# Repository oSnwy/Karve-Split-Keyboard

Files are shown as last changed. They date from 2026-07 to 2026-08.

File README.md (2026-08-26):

# Karve-Split-Keyboard

## What is this?
This is a keyboard, designed to be slightly ergonomic-consious while keeping the orginal layout and familarity of an 80% keyboard. The idea is to create a split keyboard, but with the option to connect the two havles together to create a regular 80% keyboard, inspired from the [Epomaker Split 65](https://epomaker.com/products/epomaker-split-65). Unlike the Split 65, this features an 80% layout with macro keys on the left column, an OLED 0.91 inch screen and rotary encoder on both sides. While making this keyboard, I realized that the format is really similar to the [Keychron Q11](https://www.keychron.com/products/keychron-q11-qmk-custom-mechanical-keyboard) with the macro keys and 80% layout. This keyboard features an unexploded (is that the right term) layout, maximizing desk space without comprimising on the number of keys (I need my precious function row). 

Each side of the keyboard is powered by an Pi Pico with an RP2040. The descision behind the RP2040 was due to the number of GPIO pins. Other options such as the nrf52840 and the RP2040-Zero would've worked well for this project, but the number of GPIO pins wouldn't be sufficient for all the switches and the extra features on the keyboard. The OLED screen is a general 0.91 inch 128x32px screen, with optional footprints for pull-up resistors, and the rotary encoder is a regular EC11 push switch. The switches in the keyboard are wired in a matrix with a diode on each switch. The left side is wired as an 8x6 matrix, and the right side is an 9x6 matrix. The switches themselves contain a regular mx hotswap socket which allows for easy switching between switches of the same format.

## How do I get this?
For this keyboard, you need the pcb, switches, stablizers, keycaps, two Pi Picos, two OLED screens and two rotary encoders. You should order the rest of the components using the PCBA option on [JLCPCB](https://jlcpcb.com/). You can order it using the gerbers zip file in the Gerbers file, as well as the [bom.csv](https://github.com/oSnwy/Karve-Split-Keyboard/blob/main/csv%20files/bom.csv) and the [positions-full-pcb-offset.csv](https://github.com/oSnwy/Karve-Split-Keyboard/blob/main/csv%20files/positions-full-pcb-offset.csv). Make sure you choose bottom side assembly. The switches simply slide into the top of the plate and fit into the hotswap sockets on the PCB, the stablizers are plate mounted and can be slotted into the plate, and the keycaps simply go on top of the switches. The plate uses spacers to attach to both the PCB and the case using self-tapping screws through the plate, without the need for unnessecary mounting holes on the thin plate, which may degrade it's strength. The OLED screen and Pi Pico must be soldered into the PCB using the pins, making sure they are in the correct orientation.

## CAD
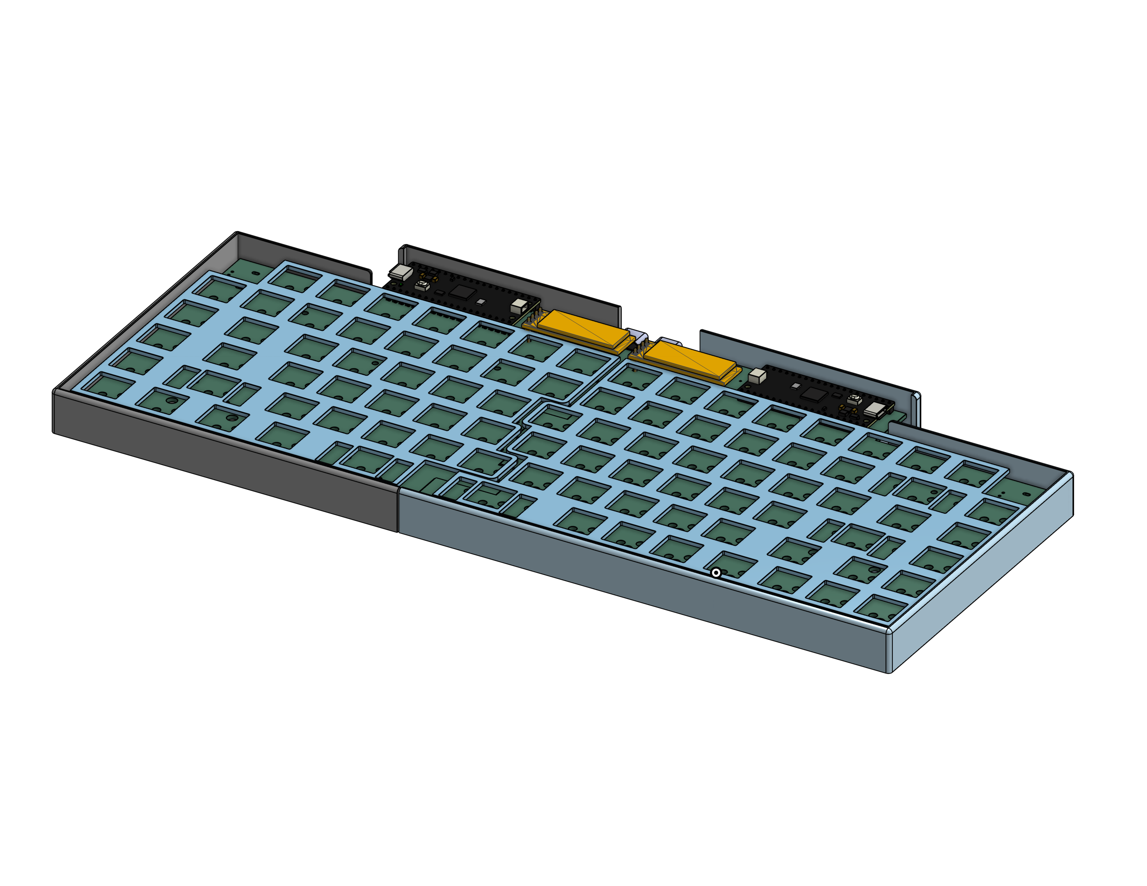
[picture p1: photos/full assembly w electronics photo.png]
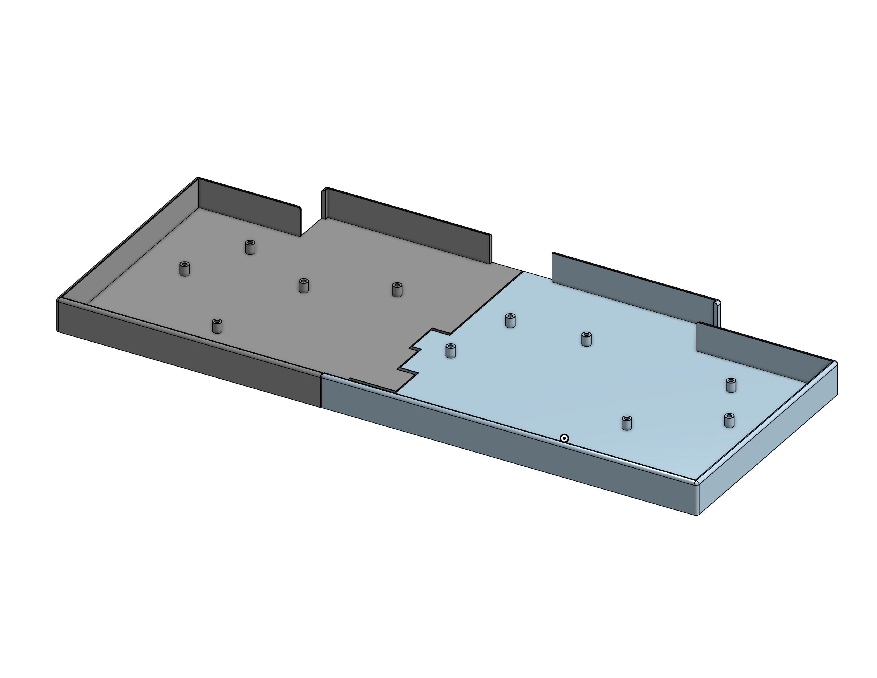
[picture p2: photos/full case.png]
|  |  |
| - | - |

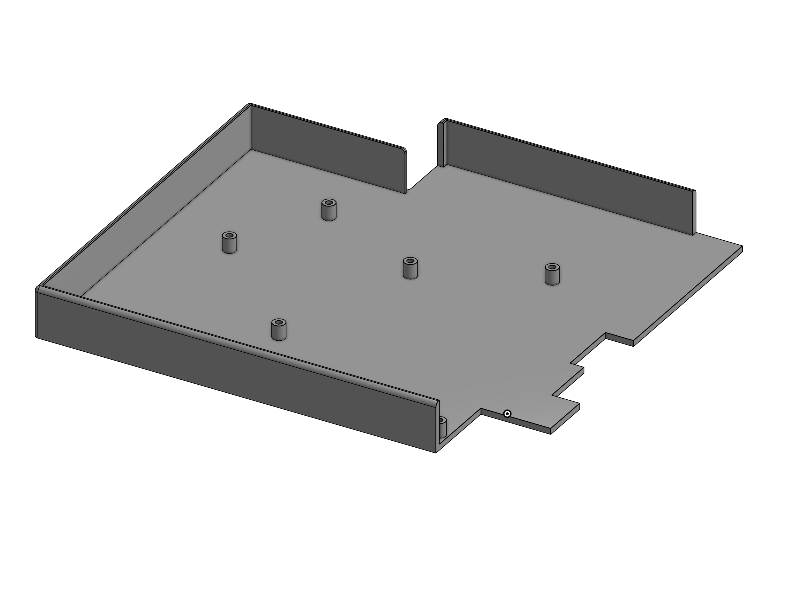
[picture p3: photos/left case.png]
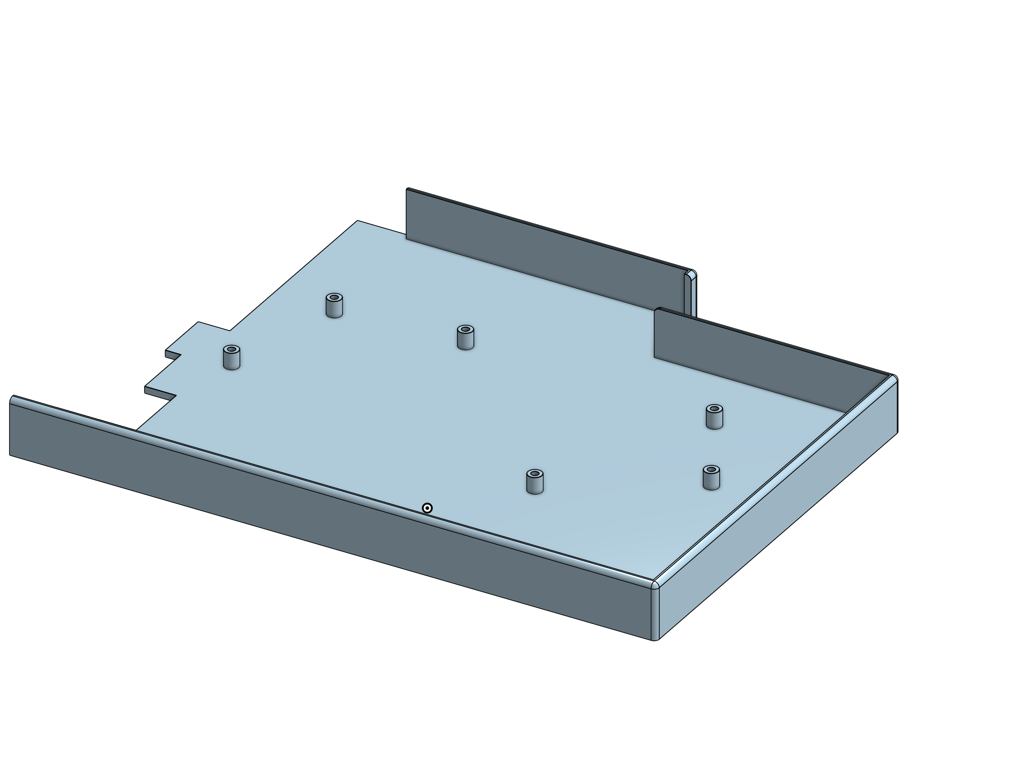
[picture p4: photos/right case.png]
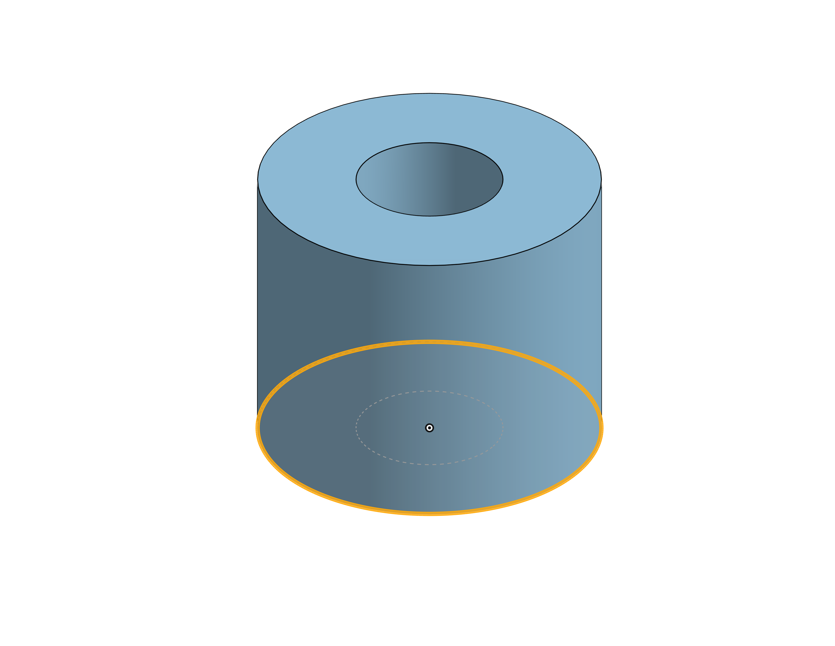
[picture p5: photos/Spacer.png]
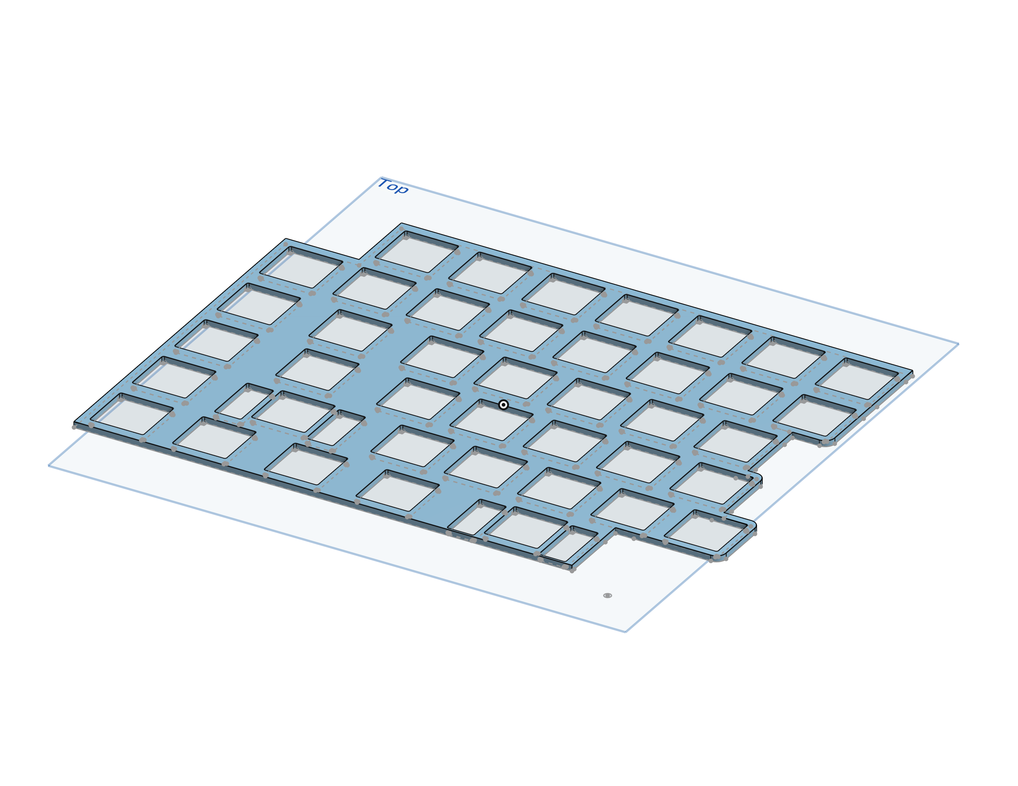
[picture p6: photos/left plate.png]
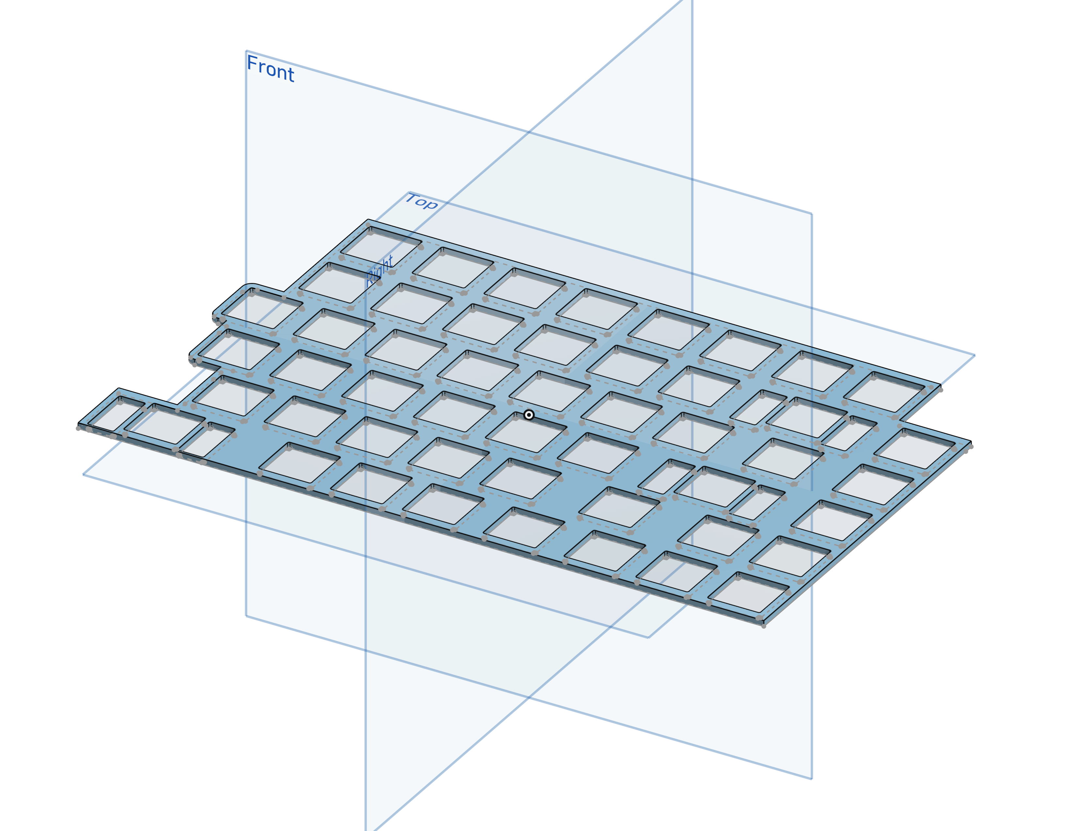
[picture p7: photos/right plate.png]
|  |  |  |  |  |
| - | - | - | - | - |

This keyboard is printed in two parts, with two different cases for each half of the PCB, as well as two plates for each half the plate and pcb are seperated by 3.5mm spacers, which are screwed in from the top of the plate to the PCB mounting holes.

[ONSHAPE LINK](https://cad.onshape.com/documents/be21bbec0bd274685795aaea/w/a2ca9be3fdf7d240859b7480/e/7d2817619a652fb02e73bd80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)

## Schematic
|  | | 
| - | - |

The schematic contains a matrix for the switches on each side, a simple 4 pin OLED screen with pull-up resistors that can be unpopulated if the screen already has pull-ups, a USB-C UART connector between the two halves, and a fuse and capacitor for the power line. The USB-C UART connections works by splitting the TX and RX lines, as well as passing the 5v through the VSYS and passing the ground through the wire.

## PCB


The PCB is a simple PCB with traces of varying widths for the purpose of each trace. The power lines and ground lines for the USB-C receptacle were 0.75mm, other ground traces and local power lines are 0.5mm. The PCB also includes M2 holes for the mounting and mousebites so the PCB can be ordered as one part.
|  | | 
| - | - |

The silkscreen art is put togetrher in a way that (hopefully) will show a full image of the tree when the split halves are put together.
## BOM

### JLCPCB BOM
 Qty | References | Component | Manufacturer / Part number | PCB footprint | JLCPCB part | Library |
|---:|---|---|---|---|---|---|
| 2 | `C2, C3` | 10 µF, 50 V, X5R, ±10% ceramic capacitor | Murata `GRM21BR61H106KE43L` | `0805` | [C440198](https://jlcpcb.com/partdetail/439567-GRM21BR61H106KE43L/C440198) | Basic |
| 92 | `D43–D134` | 1 A, 200 V fast-recovery diode | DOWO `ES1D (SOD-123FL)` | `SOD-123FL` | [C22374920](https://jlcpcb.com/partdetail/DOWO-ES1D_SOD_123FL/C22374920) | Extended |
| 2 | `F2, F3` | 500 mA resettable fuse, 33 V | BHFUSE `BSMD1206-050-33V` | `1206` | [C7202014](https://jlcpcb.com/partdetail/BHFUSE-BSMD1206_05033V/C7202014) | Extended |
| 2 | `J2, J3` | USB-C 2.0 receptacle, 16-pin | Korean Hroparts `TYPE-C-31-M-12` | `USB_C_Receptacle_HRO_TYPE-C-31-M-12` | [C165948](https://jlcpcb.com/partdetail/Korean_HropartsElec-TYPE_C_31_M12/C165948) | Extended |
| 2 | `R5, R6` | 47 Ω, ±1%, 100 mW resistor | UNI-ROYAL `0603WAF470JT5E` | `0603` | [C23182](https://jlcpcb.com/partdetail/23909-0603WAF470JT5E/C23182) | Basic |
| 90 | `SW43–SW50`, `SW52–SW92`, `SW94–SW134` | MX-compatible hot-swap socket | HanElectricity `CPG151101S11-16` | See variants below | [C41430893](https://jlcpcb.com/partdetail/HanElectricity-CPG151101S1116/C41430893) | Extended |

<details>
<summary>Hot-swap footprint variants</summary>

| Footprint | Qty |
|---|---:|
| `MX100H` | 77 |
| `MX125H` | 4 |
| `MX150H` | 2 |
| `MX175H` | 2 |
| `MX200H` | 1 |
| `MX225H` | 3 |
| `MX275H` | 1 |
| **Total** | **90** |

</details> 

### PCB and PCBA
| Component | Quantity | Notes / specification | Link | Cost |
|---|---:|---|---|---:|
| Custom split-keyboard PCB set | 1  | Left and right PCB (together) | [JLCPCB](https://jlcpcb.com/) | $64.59 USD |
| Raspberry Pi Pico | 2 | RP2040 USB-C Clone | [LINK](https://www.aliexpress.com/item/1005009245863235.html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) | $8.09 USD |
| Kailh MX-compatible hot-swap socket | 90 | HanElectricity `CPG151101S11-16`; JLCPCB/LCSC `C41430893` | [JLCPCB](https://jlcpcb.com/partdetail/HanElectricity-CPG151101S1116/C41430893) | Included in PCBA |
| Matrix diode | 92 | DOWO `ES1D`, SOD-123FL, 1 A, 200 V; JLCPCB/LCSC `C22374920` | [JLCPCB](https://jlcpcb.com/partdetail/DOWO-ES1D_SOD_123FL/C22374920) | Included in PCBA |
| USB-C 2.0 receptacle | 2 | Korean Hroparts `TYPE-C-31-M-12`; JLCPCB/LCSC `C165948` | [JLCPCB](https://jlcpcb.com/partdetail/TYPE-C-31-M-12/C165948) | Included in PCBA |
| Resettable polyfuse | 2 | BHFUSE `BSMD1206-050-33V`, 500 mA; JLCPCB/LCSC `C7202014` | [JLCPCB](https://jlcpcb.com/partdetail/BHFUSE-BSMD1206_05033V/C7202014) | Included in PCBA |
| 10 µF ceramic capacitor | 2 | Murata `GRM21BR61H106KE43L`, 0805, 50 V, X5R; JLCPCB/LCSC `C440198` | [JLCPCB](https://jlcpcb.com/partdetail/439567-GRM21BR61H106KE43L/C440198) | Included in PCBA |
| 47 Ω resistor | 2 | UNI-ROYAL `0603WAF470JT5E`, 0603, ±1%; JLCPCB/LCSC `C23182` | [JLCPCB](https://jlcpcb.com/partdetail/23909-0603WAF470JT5E/C23182) | Included in PCBA |
| 4.7 kΩ pull-up resistor | 4 optional | Through-hole; only install if the OLED modules do not include I²C pull-ups | Optional | N/A |

### Displays and Controls

| Component | Quantity | Notes / specification | Link | Cost |
|---|---:|---|---|---:|
| 0.91-inch I²C OLED display | 2 | pin order and pull ups | [AliExpress](https://www.aliexpress.com/item/1005008640108394.html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) | $7.70 USD |
| EC11-style rotary encoder with push switch | 2 | EC11 Footprint | [AliExpress](https://www.aliexpress.com/item/1005005622580163.html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) | $3.35 USD |

### Switches and Keycaps

| Component | Quantity | Notes / specification | Link | Cost |
|---|---:|---|---|---:|
| MX-compatible mechanical switch | 90 | 5-pin PCB-mount switches recommendeds | [AliExpress](https://www.aliexpress.com/item/1005005888884109.html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) | $22.53 USD |
| Keycap set | 1 set | Must cover the full split layout and split spacebar | [AliExpress](https://www.aliexpress.com/item/1005009105824301.html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) | $27.45 USD |
| Stabilizers | As required | Required for stabilized keys | [AliExpress](https://www.aliexpress.com/item/1005005793408621.html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) | $10.72 USD |

### Case, Plate, and Mounting Hardware

| Component | Quantity | Notes / specification | Link | Cost |
|---|---:|---|---|---:|
| Left keyboard plate | 1 | 3d printed | N/A | N/A |
| Right keyboard plate | 1 | 3d printed | N/A | N/A |
| Left keyboard case | 1 | 3d printed | N/A | N/A |
| Right keyboard case | 1 | 3d printed | N/A | N/A |
| Spacers | 16 | 3d pritned | N/A | N/A |

### Pico and Display Installation Hardware

| Component | Quantity | Notes / specification | Link | Cost |
|---|---:|---|---|---:|
| 1×20 pin headers | 4 strips | Two rows per Pico if soldering through-hole headers | COMES WITH PI PICO | FREE |
| 1×4 pin headers | 2 | For directly soldering the OLED modules | COMES WITH OLED | FREE |

### Cost Summary

| Category | Cost |
|---|---:|
| PCB fabrication  | $29.90 USD |
| PCB components and assembly | $34.69 USD |
| Picos, displays, and encoders | $19.14 USD |
| Switches and keycaps | $49.98 USD |
| Case, plates, and hardware | N/A |
| Cables and assembly supplies | $10.72 |
| Shipping and taxes | $41.25 USD |
| **Estimated total** | **$185.68 USD** |

## Firmware
This firmware is the preliminary firmware, and may be changed for the final finished build. It uses QMK, and can be flashed using UF2 and QMK commands.
I used this repositry as a reference: https://github.com/aminch/c64p/tree/main, as well as a couple other websites.

The firmware is grouped under the firmware file in the repositry.
It includes:
| File | Purpose |
| - | - |
| info.json | tells the computer what keyboard/mcu, as well as the USB type. |
| rules.mk | tells the computer what QMK features should be used, such as the I2C OLED. |
| mcuconf.h | enables the rp2040 I2C hardware for the OLED screens. |
| halconf.h | also used to enable the I2C for the OLED screens. |
| config.h | used to define all the pins on the picos for both the left and right split halves, as well as other features such as debounce time, OLED brightness, etc. |
| keymap.c | used to define the keymap as well as the OLED, encoders, as well as layers. |

### rules.mk: 
``` C
MCU = RP2040
BOARD = GENERIC_RP_RP2040
BOOTLOADER = rp2040

ENCODER_ENABLE = yes
OLED_ENABLE = yes
OLED_DRIVER = ssd1306
OLED_TRANSPORT = i2c
```
These lines are used to define the MCU, board, as well as enable rotary encoders and OLED screens.

### config.h: 
``` C
#define DIODE_DIRECTION COL2ROW

#define MATRIX_ROW_PINS { GP8, GP9, GP10, GP11, GP12, GP13 }
#define MATRIX_COL_PINS { GP0, GP1, GP2, GP3, GP4, GP5, GP6, GP7, NO_PIN }

#define MATRIX_ROW_PINS_RIGHT { GP5, GP4, GP3, GP2, GP1, GP0 }
#define MATRIX_COL_PINS_RIGHT { GP14, GP13, GP12, GP11, GP10, GP9, GP8, GP7, GP6 }

#define ENCODER_A_PINS { GP20 }
#define ENCODER_B_PINS { GP21 }
#define ENCODER_A_PINS_RIGHT { GP20 }
#define ENCODER_B_PINS_RIGHT { GP21 }

#define SERIAL_USART_FULL_DUPLEX
#define SERIAL_USART_TX_PIN GP16
#define SERIAL_USART_RX_PIN GP17

#define I2C_DRIVER I2CD1
#define I2C1_SDA_PIN GP18
#define I2C1_SCL_PIN GP19
```
This is used to define what each pin is used for, such as the matrix, encoders, as bwell as TX/RX and pins used for the OLED screen etc. The RX/TX are crossed through the USB port, so both sides can have the same RX/TX pins. 

``` C
#define EE_HANDS
```
This means that both of the source codes are the same for both the left and right side.

### keymap.c:
``` C
const uint16_t PROGMEM keymaps[][MATRIX_ROWS][MATRIX_COLS] = {
    [_BASE] = {
        { KC_MUTE, KC_ESC,  KC_F1,   KC_F2,   KC_F3,   KC_F4,   KC_F5,   KC_F6,   KC_NO },
        { KC_F13,  KC_GRV,  KC_1,    KC_2,    KC_3,    KC_4,    KC_5,    KC_6,    KC_NO },
        { KC_F14,  KC_TAB,  KC_Q,    KC_W,    KC_E,    KC_R,    KC_T,    KC_NO,   KC_NO },
        { KC_F15,  KC_CAPS, KC_A,    KC_S,    KC_D,    KC_F,    KC_G,    KC_NO,   KC_NO },
        { KC_F16,  KC_LSFT, KC_Z,    KC_X,    KC_C,    KC_V,    KC_B,    KC_NO,   KC_NO },
        { KC_F17,  KC_LCTL, KC_LGUI, KC_LALT, KC_SPC,  KC_NO,   KC_NO,   KC_NO,   KC_NO },
        { KC_F7,   KC_F8,   KC_F9,   KC_F10,  KC_F11,  KC_F12,  KC_INS,  KC_DEL,  KC_MUTE },
        { KC_NO,   KC_7,    KC_8,    KC_9,    KC_0,    KC_MINS, KC_EQL,  KC_BSPC, KC_PGUP },
        { KC_Y,    KC_U,    KC_I,    KC_O,    KC_P,    KC_LBRC, KC_RBRC, KC_BSLS, KC_PGDN },
        { KC_NO,   KC_H,    KC_J,    KC_K,    KC_L,    KC_SCLN, KC_QUOT, KC_ENT,  KC_HOME },
        { KC_NO,   KC_N,    KC_M,    KC_COMM, KC_DOT,  KC_SLSH, KC_RSFT, KC_UP,   KC_END },
        { KC_NO,   KC_SPC,  KC_RALT, KC_RGUI, MO(_FN), KC_RCTL, KC_LEFT, KC_DOWN, KC_RGHT }
    },
    [_FN] = {
        { _______, QK_BOOT, _______, _______, _______, _______, _______, _______, KC_NO },
        { _______, _______, _______, _______, _______, _______, _______, _______, KC_NO },
        { _______, _______, _______, _______, _______, _______, _______, KC_NO,   KC_NO },
        { _______, _______, _______, _______, _______, _______, _______, KC_NO,   KC_NO },
        { _______, _______, _______, _______, _______, _______, _______, KC_NO,   KC_NO },
        { _______, _______, _______, _______, _______, KC_NO,   KC_NO,   KC_NO,   KC_NO },
        { _______, _______, _______, _______, _______, _______, _______, _______, _______ },
        { KC_NO,   _______, _______, _______, _______, _______, _______, _______, _______ },
        { _______, _______, _______, _______, _______, _______, _______, _______, _______ },
        { KC_NO,   _______, _______, _______, _______, _______, _______, _______, _______ },
        { KC_NO,   _______, _______, _______, _______, _______, _______, _______, _______ },
        { KC_NO,   _______, _______, _______, _______, _______, _______, _______, _______ }
    }
};
```
The keymap file allows us to assign each matrix to a specific key by using these arrays, as well as the function layer. Right now these keys are in a tentative map, but it can easily be changed later.

``` C
bool encoder_update_user(uint8_t index, bool clockwise) {
    if (index == 0) {
        if (clockwise){
            tap_code(KC_PGDN);
        }else{
            tap_code(KC_PGUP);
        }
    } else {
        if (clockwise){
            tap_code(KC_VOLU);
        }else{
            tap_code(KC_VOLD);
        }
    } 
    return false;
}
```
This simply assigns the rotary encoders left and right turns to a key.

``` C
#ifdef OLED_ENABLE

oled_rotation_t oled_init_user(oled_rotation_t rotation) {
    return rotation;
}

bool oled_task_user(void) {
    oled_write_ln_P(PSTR("KARVE"), false);

    if (is_keyboard_left()) {
        oled_write_ln_P(PSTR("LEFT"), false);
    } else {
        oled_write_ln_P(PSTR("RIGHT"), false);
    }

    if (is_keyboard_master()) {
        oled_write_ln_P(PSTR("MASTER"), false);
    } else {
        oled_write_ln_P(PSTR("SLAVE"), false);
    }

    oled_write_P(PSTR("LAYER "), false);
    oled_write_char('0' + get_highest_layer(layer_state), false);

    return false;
}

#endif
```
This displays "KARVE LEFT MASTER" or "KARVE RIGHT SLAVE" on the OLED screens depending on the split half. This is can easily changed to other options later.

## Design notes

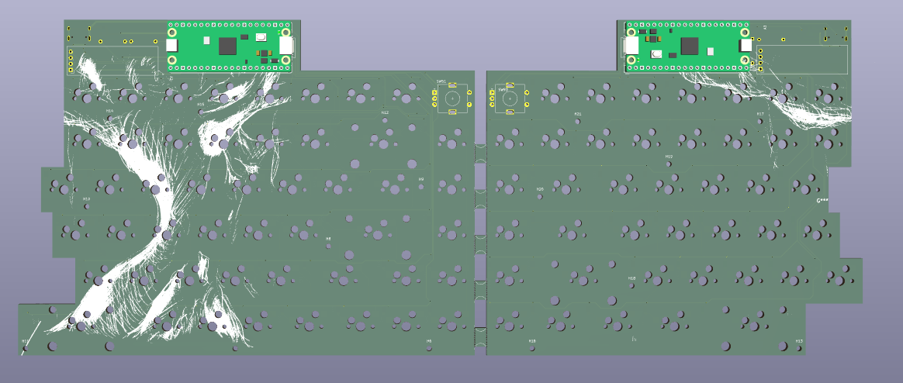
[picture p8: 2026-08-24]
photos/PCB model.png

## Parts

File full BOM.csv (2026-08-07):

Category | Component | Quantity | Notes / specification | Link | Cost
PCB and PCBA | Custom split-keyboard PCB set | 1 | Left and right PCB (together) | https://jlcpcb.com/ | $64.59 USD
PCB and PCBA | Raspberry Pi Pico | 2 | RP2040 USB-C Clone | https://www.aliexpress.com/item/1005009245863235.html?mp=1 | $8.09 USD
PCB and PCBA | Kailh MX-compatible hot-swap socket | 90 | HanElectricity CPG151101S11-16; JLCPCB/LCSC C41430893 | https://jlcpcb.com/partdetail/HanElectricity-CPG151101S1116/C41430893 | Included in PCBA
PCB and PCBA | Matrix diode | 92 | DOWO ES1D, SOD-123FL, 1 A, 200 V; JLCPCB/LCSC C22374920 | https://jlcpcb.com/partdetail/DOWO-ES1D_SOD_123FL/C22374920 | Included in PCBA
PCB and PCBA | USB-C 2.0 receptacle | 2 | Korean Hroparts TYPE-C-31-M-12; JLCPCB/LCSC C165948 | https://jlcpcb.com/partdetail/TYPE-C-31-M-12/C165948 | Included in PCBA
PCB and PCBA | Resettable polyfuse | 2 | BHFUSE BSMD1206-050-33V, 500 mA; JLCPCB/LCSC C7202014 | https://jlcpcb.com/partdetail/BHFUSE-BSMD1206_05033V/C7202014 | Included in PCBA
PCB and PCBA | 10 µF ceramic capacitor | 2 | Murata GRM21BR61H106KE43L, 0805, 50 V, X5R; JLCPCB/LCSC C440198 | https://jlcpcb.com/partdetail/439567-GRM21BR61H106KE43L/C440198 | Included in PCBA
PCB and PCBA | 47 Ω resistor | 2 | UNI-ROYAL 0603WAF470JT5E, 0603, ±1%; JLCPCB/LCSC C23182 | https://jlcpcb.com/partdetail/23909-0603WAF470JT5E/C23182 | Included in PCBA
PCB and PCBA | 4.7 kΩ pull-up resistor | 4 optional | Through-hole; only install if the OLED modules do not include I²C pull-ups | Optional | N/A
Displays and Controls | 0.91-inch I²C OLED display | 2 | Pin order and pull ups | https://www.aliexpress.com/item/1005008640108394.html?mp=1 | $7.70 USD
Displays and Controls | EC11-style rotary encoder with push switch | 2 | EC11 Footprint | https://www.aliexpress.com/item/1005005622580163.html?mp=1 | $3.35 USD
Switches and Keycaps | MX-compatible mechanical switch | 90 | 5-pin PCB-mount switches recommended | https://www.aliexpress.com/item/1005005888884109.html?mp=1 | $22.53 USD
Switches and Keycaps | Keycap set | 1 set | Must cover the full split layout and split spacebar | https://www.aliexpress.com/item/1005009105824301.html?mp=1 | $27.45 USD
Switches and Keycaps | Stabilizers | As required | Required for stabilized keys | https://www.aliexpress.com/item/1005005793408621.html?mp=1 | $10.72 USD
Case, Plate, and Mounting Hardware | Left keyboard plate | 1 | 3D printed | N/A | N/A
Case, Plate, and Mounting Hardware | Right keyboard plate | 1 | 3D printed | N/A | N/A
Case, Plate, and Mounting Hardware | Left keyboard case | 1 | 3D printed | N/A | N/A
Case, Plate, and Mounting Hardware | Right keyboard case | 1 | 3D printed | N/A | N/A
Case, Plate, and Mounting Hardware | Spacer | 16 | 3D printed | N/A | N/A
Pico and Display Installation Hardware | 1×20 pin headers | 4 strips | Two rows per Pico if soldering through-hole headers | COMES WITH PI PICO | FREE
Pico and Display Installation Hardware | 1×4 pin headers | 2 | For directly soldering the OLED modules | COMES WITH OLED | FREE

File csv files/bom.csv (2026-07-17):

JLCPCB BOM Tool - BOM Matching
BOM name：bom-JLCPCB Assembly Order.xlsx |  |  | Download Time：2026-07-17 08:58:46 |  |  |  | * Our matching results are updated in real-time, but stock and prices may change. If it's been over 24 hours, please re-match before placing your order.
PCB Assembled Qty：5 |  |  | Est. Total Price：49.7276
Your BOM |  |  |  |  | Matched Parts |  |  |  |  |  |  | Order Information
Top Designator | Bottom Designator | Comment | Footprint | JLCPCB Part # | Matches | Part # | Manufacturer | Footprint | Description | Category | Warning | JLCPCB Part # | Product link | Lib Type | Qty | Source | Total Price ($)
 | C2,C3 | 10uF | 0805 |  | Select by System | GRM21BR61H106KE43L | Murata Electronics | 0805 | 10uF 50V X5R ±10% 0805 Multilayer Ceramic Capacitors MLCC - SMD/SMT ROHS | Multilayer Ceramic Capacitors MLCC - SMD/SMT |  | C440198 | https://jlcpcb.com/partdetail/439567-GRM21BR61H106KE43L/C440198 | Basic | 4 | 4 JLCPCB | 0.564
 | D100,D101,D102,D103,D104,D105,D106,D107,D108,D109,D110,D111,D112,D113,D114,D115,D116,D117,D118,D119,D120,D121,D122,D123,D124,D125,D126,D127,D128,D129,D130,D131,D132,D133,D134,D43,D44,D45,D46,D47,D48,D49,D50,D51,D52,D53,D54,D55,D56,D57,D58,D59,D60,D61,D62,D63,D64,D65,D66,D67,D68,D69,D70,D71,D72,D73,D74,D75,D76,D77,D78,D79,D80,D81,D82,D83,D84,D85,D86,D87,D88,D89,D90,D91,D92,D93,D94,D95,D96,D97,D98,D99 | D | D_SOD-123 |  | Select by Customer | ES1D(SOD-123FL) | DOWO | SOD-123FL | -55℃~+150℃ 1 Independent 1.3V@1A 1A 200V 35ns 5uA SOD-123FL Fast Recovery / High Efficiency Diodes ROHS | Fast Recovery / High Efficiency Diodes |  | C22374920 | https://jlcpcb.com/partdetail/DOWO-ES1D_SOD_123FL/C22374920 | Extended | 188 | 188 JLCPCB | 2.1056
 | F2,F3 | 500mA | 1206 |  | Select by System | BSMD1206-050-33V | BHFUSE | 1206 | -40℃~+85℃ 1.9mm 150mΩ 1A 1mm 3.6mm 33V 40A 500mA 800mW 850mΩ 1206 Resettable Fuses ROHS | Resettable Fuses |  | C7202014 | https://jlcpcb.com/partdetail/BHFUSE-BSMD1206_05033V/C7202014 | Extended | 8 | 8 JLCPCB | 0.5488
 | J2,J3 | USB_C_Receptacle_USB2.0_16P | USB_C_Receptacle_HRO_TYPE-C-31-M-12 |  | Select by Customer | TYPE-C-31-M-12 | Korean Hroparts Elec | SMD | -30℃~+80℃ 1 10,000 cycles 16P 20V 5A 7.35mm Female Surface Mount, Right Angle Type-C SMD USB Connectors ROHS | USB Connectors |  | C165948 | https://jlcpcb.com/partdetail/Korean_HropartsElec-TYPE_C_31_M12/C165948 | Extended | 4 | 4 JLCPCB | 0.7368
 | R5,R6 | 47R | 0603 |  | Unconfirmed | 0603WAF470JT5E | UNI-ROYAL(Uniroyal Elec) | 0603 | -55℃~+155℃ 100mW 47Ω 75V Thick Film Resistor ±1% ±100ppm/℃ 0603 Chip Resistor - Surface Mount ROHS | Chip Resistor - Surface Mount | 1.The comment (0603WAF470JT5E) of this part does not match the one (47R) provided in your BOM. Please confirm; | C23182 | https://jlcpcb.com/partdetail/23909-0603WAF470JT5E/C23182 | Basic | 4 | 4 JLCPCB | 0.0344
 | SW58 | SW_Push | MX200H |  | Select by Customer | CPG151101S11-16 | HanElectricity | SMD,14.5x5.9mm | 12V 2 3000gf 5,000 cycles SMD,14.5x5.9mm Mechanical Keyboard Shaft ROHS | Mechanical Keyboard Shaft | 1.Multiple lines in the BOM have been matched to the same part. Please check if the matching is correct. ; | C41430893 | https://jlcpcb.com/partdetail/HanElectricity-CPG151101S1116/C41430893 | Extended | 180 | 180 JLCPCB | 6.534
 | SW85 | SW_Push | MX275H |  | Select by Customer | CPG151101S11-16 | HanElectricity | SMD,14.5x5.9mm | 12V 2 3000gf 5,000 cycles SMD,14.5x5.9mm Mechanical Keyboard Shaft ROHS | Mechanical Keyboard Shaft | 1.Multiple lines in the BOM have been matched to the same part. Please check if the matching is correct. ; | C41430893 | https://jlcpcb.com/partdetail/HanElectricity-CPG151101S1116/C41430893 | Extended | 180 | 180 JLCPCB | 6.534
 | SW100,SW101,SW102,SW103,SW104,SW105,SW106,SW107,SW108,SW109,SW111,SW112,SW113,SW114,SW115,SW116,SW118,SW119,SW120,SW121,SW122,SW123,SW125,SW126,SW127,SW128,SW129,SW130,SW43,SW44,SW45,SW46,SW47,SW48,SW49,SW50,SW52,SW53,SW54,SW55,SW56,SW57,SW59,SW60,SW61,SW62,SW63,SW64,SW65,SW66,SW68,SW69,SW70,SW71,SW72,SW73,SW74,SW76,SW77,SW78,SW79,SW80,SW81,SW83,SW84,SW86,SW87,SW88,SW90,SW91,SW92,SW94,SW95,SW96,SW97,SW98,SW99 | SW_Push | MX100H |  | Select by Customer | CPG151101S11-16 | HanElectricity | SMD,14.5x5.9mm | 12V 2 3000gf 5,000 cycles SMD,14.5x5.9mm Mechanical Keyboard Shaft ROHS | Mechanical Keyboard Shaft | 1.Multiple lines in the BOM have been matched to the same part. Please check if the matching is correct. ; | C41430893 | https://jlcpcb.com/partdetail/HanElectricity-CPG151101S1116/C41430893 | Extended | 180 | 180 JLCPCB | 6.534
 | SW110,SW67 | SW_Push | MX150H |  | Select by Customer | CPG151101S11-16 | HanElectricity | SMD,14.5x5.9mm | 12V 2 3000gf 5,000 cycles SMD,14.5x5.9mm Mechanical Keyboard Shaft ROHS | Mechanical Keyboard Shaft | 1.Multiple lines in the BOM have been matched to the same part. Please check if the matching is correct. ; | C41430893 | https://jlcpcb.com/partdetail/HanElectricity-CPG151101S1116/C41430893 | Extended | 180 | 180 JLCPCB | 6.534
 | SW117,SW82 | SW_Push | MX175H |  | Select by Customer | CPG151101S11-16 | HanElectricity | SMD,14.5x5.9mm | 12V 2 3000gf 5,000 cycles SMD,14.5x5.9mm Mechanical Keyboard Shaft ROHS | Mechanical Keyboard Shaft | 1.Multiple lines in the BOM have been matched to the same part. Please check if the matching is correct. ; | C41430893 | https://jlcpcb.com/partdetail/HanElectricity-CPG151101S1116/C41430893 | Extended | 180 | 180 JLCPCB | 6.534
 | SW124,SW134,SW75 | SW_Push | MX225H |  | Select by Customer | CPG151101S11-16 | HanElectricity | SMD,14.5x5.9mm | 12V 2 3000gf 5,000 cycles SMD,14.5x5.9mm Mechanical Keyboard Shaft ROHS | Mechanical Keyboard Shaft | 1.Multiple lines in the BOM have been matched to the same part. Please check if the matching is correct. ; | C41430893 | https://jlcpcb.com/partdetail/HanElectricity-CPG151101S1116/C41430893 | Extended | 180 | 180 JLCPCB | 6.534
 | SW131,SW132,SW133,SW89 | SW_Push | MX125H |  | Select by Customer | CPG151101S11-16 | HanElectricity | SMD,14.5x5.9mm | 12V 2 3000gf 5,000 cycles SMD,14.5x5.9mm Mechanical Keyboard Shaft ROHS | Mechanical Keyboard Shaft | 1.Multiple lines in the BOM have been matched to the same part. Please check if the matching is correct. ; | C41430893 | https://jlcpcb.com/partdetail/HanElectricity-CPG151101S1116/C41430893 | Extended | 180 | 180 JLCPCB | 6.534

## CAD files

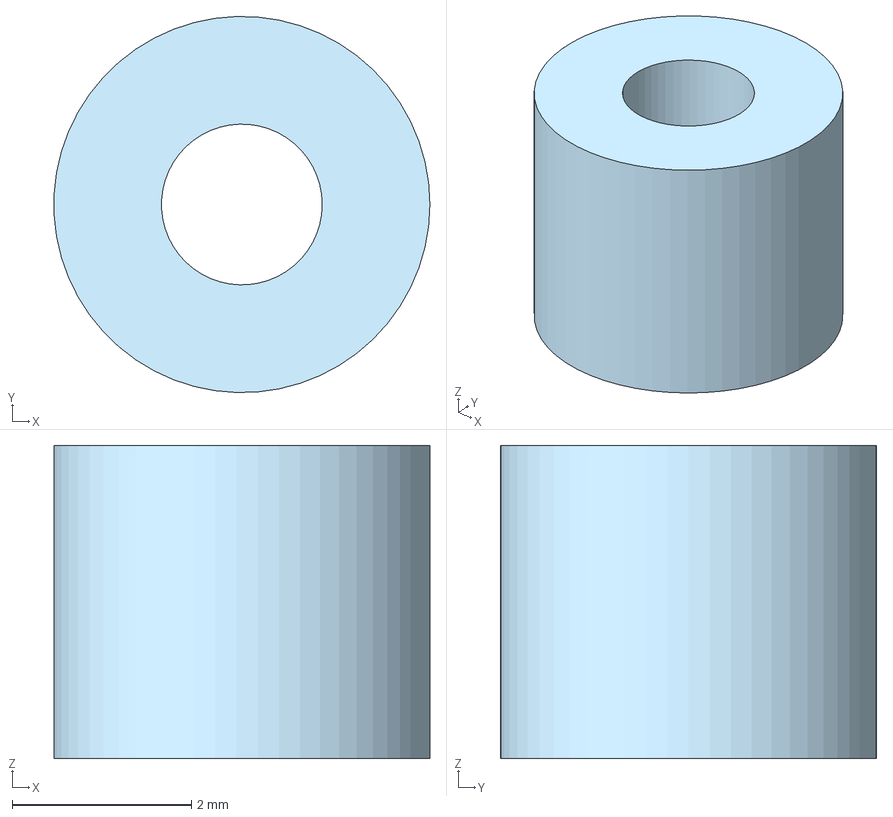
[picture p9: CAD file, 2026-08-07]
3d models/case and plate STEP files/Spacer.step
4.20 x 4.20 x 3.50 mm

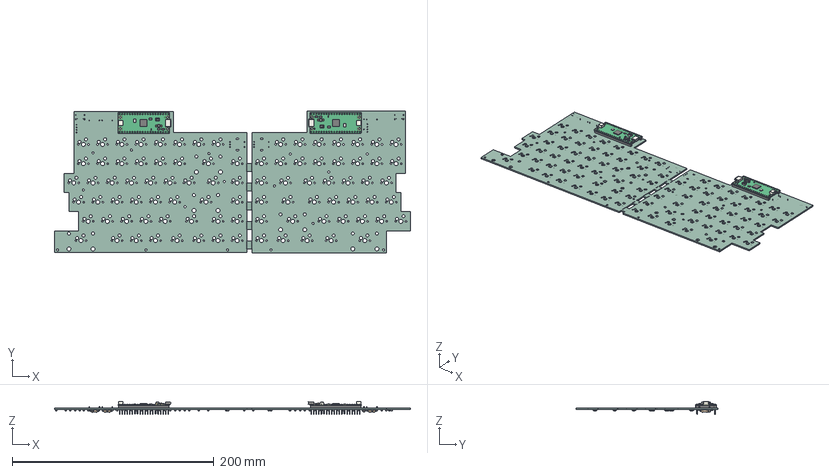
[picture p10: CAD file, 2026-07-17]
3d models/PCB models/pcb.step
352.7 x 140.2 x 12.8 mm
RaspberryPi_Pico_H_Module_KiCad x 2
RaspberryPi_Pico_Header_DIP-40_H2.54mm_KiCad x 2
D_SOD-123 x 92
Fuse_1206_3216Metric x 2
C_0805_2012Metric x 2
R_Axial_DIN0207_L63mm_D25mm_P1016mm_Horizontal x 4
R_0603_1608Metric x 2
karve-split_PCB

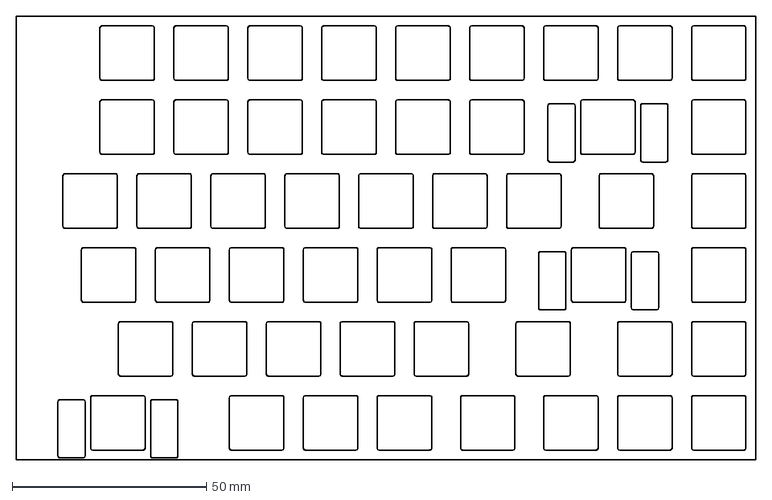
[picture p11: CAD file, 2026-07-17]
dxf files/right.dxf
190.5 x 114.3 mm

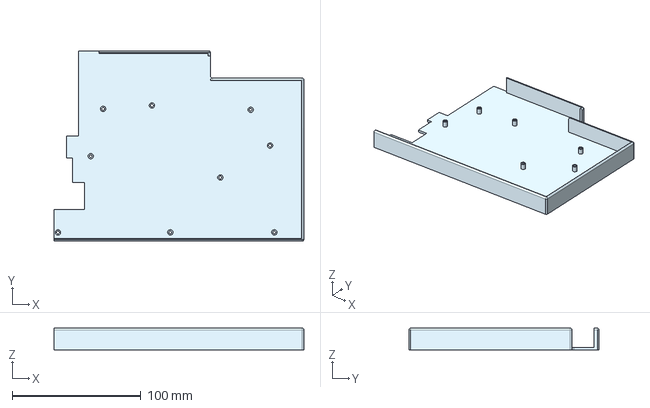
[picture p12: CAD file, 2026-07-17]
3d models/case and plate STEP files/right case.step
194.6 x 148.2 x 17.0 mm

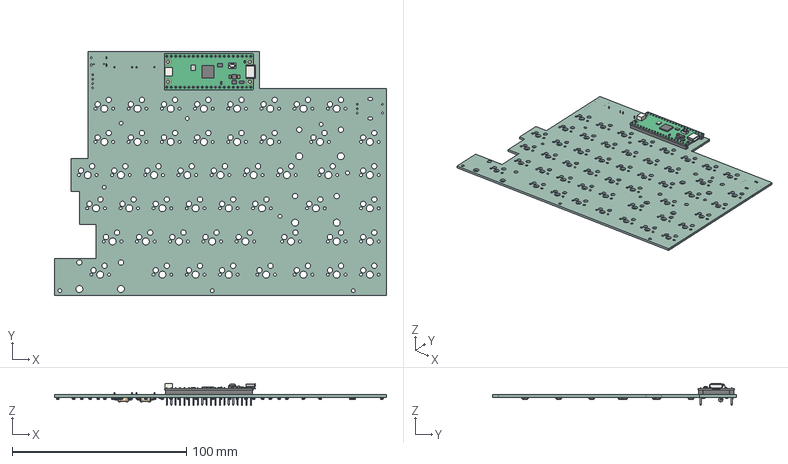
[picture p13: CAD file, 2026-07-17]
3d models/PCB models/right pcb.step
190.6 x 140.2 x 12.8 mm
RaspberryPi_Pico_H_Module_KiCad
RaspberryPi_Pico_Header_DIP-40_H2.54mm_KiCad
D_SOD-123 x 50
Fuse_1206_3216Metric
C_0805_2012Metric
R_Axial_DIN0207_L63mm_D25mm_P1016mm_Horizontal x 2
R_0603_1608Metric
karve-split_PCB

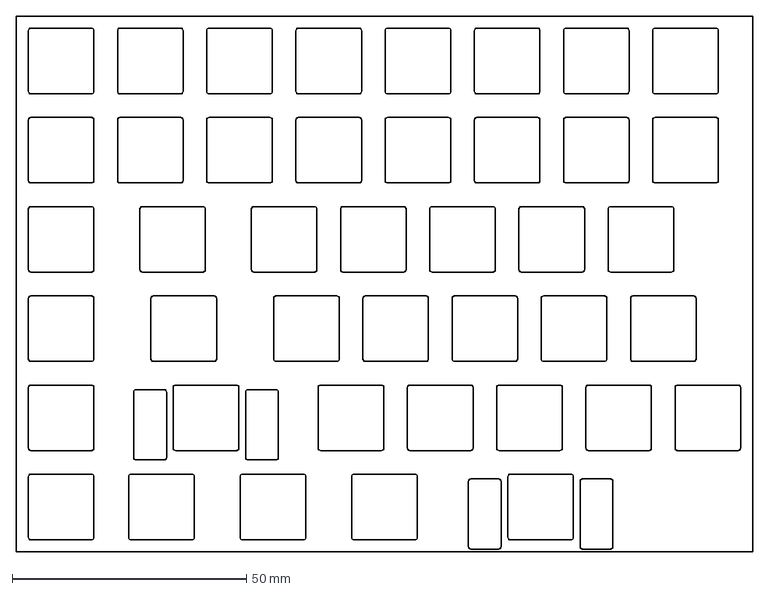
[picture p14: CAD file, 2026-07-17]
dxf files/left.dxf
157.2 x 114.3 mm

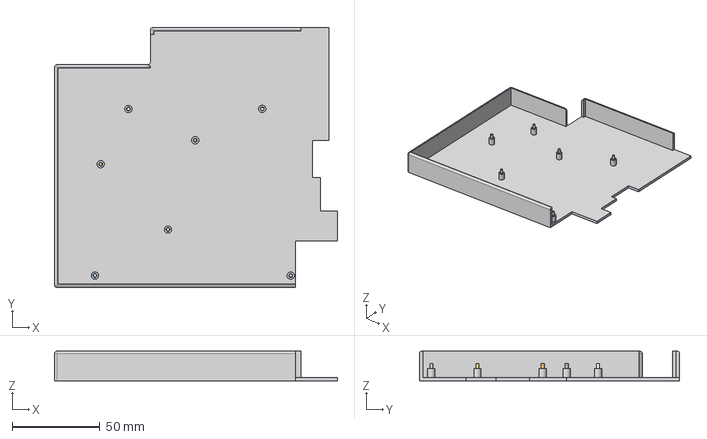
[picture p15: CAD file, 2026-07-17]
3d models/case and plate STEP files/left case.step
161.2 x 148.2 x 17.0 mm

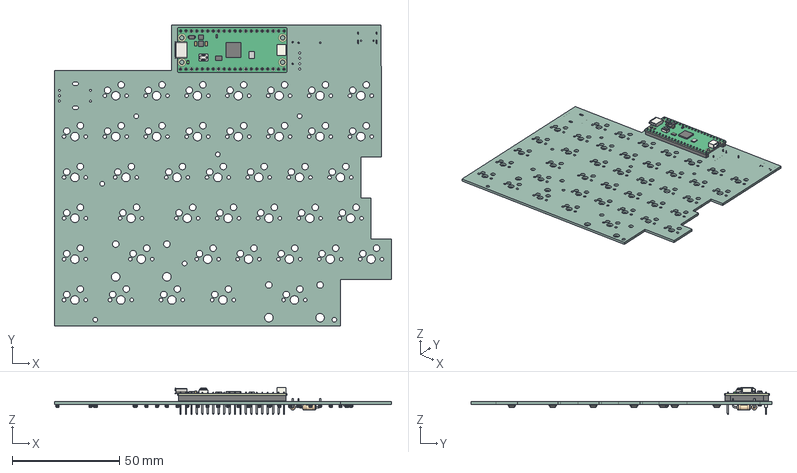
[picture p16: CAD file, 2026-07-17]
3d models/PCB models/left pcb.step
157.2 x 140.2 x 12.8 mm
RaspberryPi_Pico_H_Module_KiCad
RaspberryPi_Pico_Header_DIP-40_H2.54mm_KiCad
D_SOD-123 x 42
C_0805_2012Metric
R_0603_1608Metric
Fuse_1206_3216Metric
R_Axial_DIN0207_L63mm_D25mm_P1016mm_Horizontal x 2
karve-split_PCB

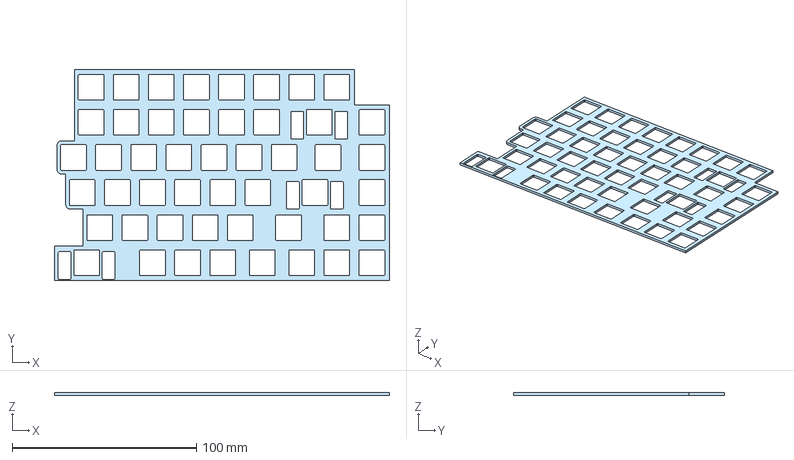
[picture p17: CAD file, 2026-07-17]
3d models/case and plate STEP files/right plate.step
181.8 x 114.3 x 1.50 mm

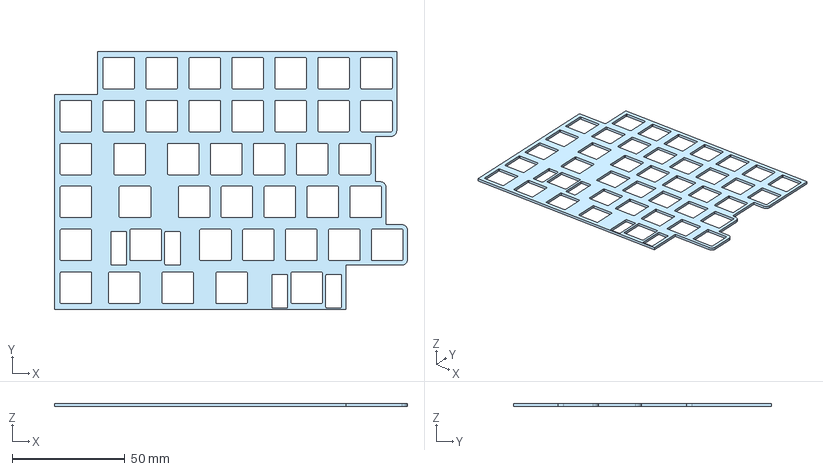
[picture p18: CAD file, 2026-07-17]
3d models/case and plate STEP files/left plate.step
156.6 x 114.3 x 1.50 mm

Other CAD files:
3d models/case and plate STL files/Spacer.stl
3d models/case and plate STL files/left case.stl
3d models/case and plate STL files/left plate.stl
3d models/case and plate STL files/right case.stl
3d models/case and plate STL files/right plate.stl

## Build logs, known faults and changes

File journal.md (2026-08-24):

## Journals 
TOTAL TIME: 31.8h

### Journal #1: Left Schematic 1.1h
Jul 10, 2026, 11:39 PM

LAPSE LINK: https://lapse.hackclub.com/timelapse/AHXKs98OKrFT

I used the Pi Pico to wire the left side of my split keyboard PCB. The idea is to have a normal 80% keyboard that can be split into two separate halves when needed. I plan to have a rotary encoder and an OLED screen on each side, which uses a lot of GPIO pins, hence the need for the Pi Pico. I plan to use a USB-C cable to connect each half, as well as a USB-C clone of the Pi Pico. However, I may change the interconnect to prevent any accidents with frying any electronics it's plugged into while live, as the interconnect would be 5V, which can damage certain electronics.


### Journal #2 : Finished Right side schematic! and fixed left side too. - 1.7h
Jul 11, 2026, 4:22 PM
LAPSE LINK: https://lapse.hackclub.com/timelapse/Qn_e6l_58baJ

RESOURCES USED:
| Resource | LINK |
| - | - |
| Pico split keyboard example | https://github.com/akaenner/picosplit/tree/main/Images |
| OLED with Pi Pico | https://www.instructables.com/How-to-Use-an-OLED-Display-With-Raspberry-Pi-Pico/ |
| Raspberry Pi Pico pinouts | https://learn.adafruit.com/getting-started-with-raspberry-pi-pico-circuitpython/pinouts |
| Pi Pico Power | https://www.penguintutor.com/electronics/pico-power |
| How to use UCB C interconnect | https://forums.raspberrypi.com/viewtopic.php?t=370405 |
| How to power two Pi Pico with one connection | https://forums.raspberrypi.com/viewtopic.php?t=362588 |
| Hackclub keeb tutorial | https://keeb.hackclub.com/docs/pcb-design/ |

While creating the right side of the split, I realized that my split interconnect was off. I deleted the resistors from the CC pins, as it's an interconnect rather than a device. I also added resistors and capacitors to the interconnect to make it more reliable. I fixed the UART connectors, as I used the SPI ones instead of the UART for the interconnect... oops. I considered using 4P4C connectors instead of the USB-C interconnect, as I don't want to accidentally plug the keyboard in with the wrong connector, but other types of connectors have the chance to short while being plugged in, which is a risk I would rather not take. I also fixed some incorrect labelling with the rotary encoders.



### Journal #3 : PCB TIME! - 5.7h
Jul 12, 2026, 10:38 PM
LAPSE LINK: https://lapse.hackclub.com/timelapse/Nm9sm-tdtZRg

Longest session of the project (so far)! It wasn't so bad as it was tedious. 
Unfortunately, the left side of the schematic was corrupted, and I had to redo it. I now have backups. I also added all the footprints, but changed the pull-up resistor diodes from SMD to THT, just in case I order an OLED screen that already contains pull-up resistors. I finalized the layout too (80% split with row of macro keys on the left).

Many of the traces were lapping, and as I wanted the form factor to be minimized, I ended up having to reroute a lot of the traces. Something that helped was rerouting some of the GPIO pins in the schematic and putting them in more favourable areas in the PCB. I added breakouts to the PCB, so I can order the entire keyboard with one PCB. It's a little larger than I would have liked, but the overall layout is the same as I imagined when I started this project. Each side of the keyboard contains an OLED screen, rotary encoder, and USB-C receptacle for the interconnect, as well as a Pi Pico each for the MCU. The wiring of the traces was a little difficult, but enough VIAs and anything will work. Mostly it was just tedious.  


### Journal #4 : PCB editing! - 1.2h
Jul 13, 2026, 1:20 PM
Unfortunately, the LAPSE session errored out on the server side, so no link today.
I switched out the PCB traces for the VSYS and GND with larger-width traces (0.4mm to 0.75mm) so the traces could withstand the current coming to and from the power sources. I also rerouted the GND and power traces to be wired in parallel rather than series, in order to reduce the current in the traces. I had to rewire some other traces to make room for the wider ones, but there was enough room that no significant changes were needed.


### Journal #5 : PCB editing (final time?) - 2.3h
Jul 13, 2026, 7:35 PM
LAPSE LINK: https://lapse.hackclub.com/timelapse/eDsbnPfNF0BU

To make the PCB ready for assembly, I moved 100+ vias off of pads, choosing to use "dog bone" connections instead. I added solder paste to all the footprints of the key switches for the hotswap sockets, as it is needed for the PCBA. I also moved all the PCBA objects like the fuse, USB-C connector and other objects to be on the bottom of the PCB, rather than the top, so that the PCBA can be assembled on one side only.


I tried to add the hotswap sockets, but they are misaligned with the holes of the switch footprints. The CPL file needs to be edited so that the positions of the hotswap sockets are offset to the correct values.


### Journal #6 : gotta edit them all (CPL this time) - 0.6h
Jul 13, 2026, 9:10 PM
I forgot to start lapse :( no link this time. Luckily, it was only trial and error and didn't take too long.
Due to differences between the switch socket and the footprint, I had to offset the switch footprint and the center of the hotswap sockets to match the pads on the back of the PCB. If anyone needs the exact numbers, I offset the switch X by -0.635mm and the Y by 3.81mm, and rotated them 180 degrees. This was basically educated guesswork, using trial and error with the dimensions of the two footprints until it looked about right.


### Journal #7 : 3D Modeling and PCB editing - 2.8h
Jul 14, 2026, 4:53 PM
LAPSE LINK: https://lapse.hackclub.com/timelapse/LoeWm3Z8hO0E

PCB Editing!.. For the last time. No promises.


I wanted to make the total dimensions of the PCB footprint smaller, so I changed the position of the mousebites to be on the opposite side, so that the left and right PCBs were swapped in production. This really didn't change the price much, unfortunately. I also added some mounting holes for the PCB to attach to the case or an optional plate. I did have to rewire some traces to make room for the mounting holes, though.



I also made the cases in OnShape. These cases are just simple covers for the bottom of the PCB. The PCB sits on little studs on the bottom of the case, and the rest of the items can be mounted on top of the PCB.

### Journal #8 : 3d modeling 2.0 - 1.2h
Jul 14, 2026, 9:34 PM
LAPSE LINK:https://lapse.hackclub.com/timelapse/20pD51KX2Rlz


Using this keyboard layout editor and ai03's plate generator, I generated a DXF file for the two plates needed for the keyboard. Using the DFX, I imported the sketch into Onshape and adjusted certain elements of the generated DFX sketch, such as the areas where the two halves meet and the space for the rotary encoder. It was pretty straightforward, but I did accidentally deleted one of the sketches by accident, and both sides' layout had to be changed a tiny bit.
| Resource | LINK |
| - | - |
| Layout Editor | https://www.keyboard-layout-editor.com/#/ |
| Plate Generator | https://kbplate.ai03.com/ |

### Journal #9 : BOM and CPL editing - 1.7h
Jul 16, 2026, 9:26 PM
No lapse link today cause I thought this would take less time than it did :(. Turns out everything takes longer when you think it's straightforward.
Because I changed the layout of the mousebites on the PCB, I had to change the offset of the positions of the CPL again... I gotta write a script to automate this. It's such a pain. I also edited the BOM of the PCB through JLCPCB, which includes the link, part number, etc. Despite that being pretty easy, JLCPCB allows download of the BOM after choosing the parts, but only in .xls format. Converting this from .xls to .csv is pretty straightforward, as long as you can view the .xls format. I used a random online editor for the .xls and VS Code for the .csv file.


### Journal #10 : PCB editing for shipping costs - 2.4h
Jul 17, 2026, 6:53 PM
I was going through some sensitive information on my JLCPCB account and shipping accounts, so I didn't use Lapse this time.


I wanted to lower the shipping costs of the PCB, as it was 40% of the total cost of the PCB. I attempted to split the PCB into two separate halves instead of one with mousebites to reduce the total dimensions of the PCB, and update the BOM and CPL of both of the halves. However, despite all these changes, the total cost of the PCBs actually increased, making all the work rather fruitless. I did, however, manage to find a couple of traces that were too close for the tolerances of the pads.

### Journal #11 : Github - 3.5h
Jul 17, 2026, 9:12 PM
I'm not sure if this counts towards hours worked, but it makes sense to journal it anyway. 

I updated the entire README, as well as added the BOM and CPL. I also added all the photos, as well as created a BOM in the README, including links, prices, notes/specifications, and a short tutorial on how to create the keyboard, as well as my process. The README contains all the resources used, as well as photos of all the files and the process.

### Journal #11 : Ship Changes - 5.6h
Aug 7, 2026, 6:59 PM
I wrote some preliminary firmware for the keyboard, including some temporary placeholders for the OLED screens and rotary encoder behaviours. The keyboard firmware uses QMK, as well as UF2 to flash the firmware.

I added some spacers, as well as changed the case of the PCB to make the mounting holes recessed rather than pins. This way, the plate can be directly screwed in using tap-in screws from the top of the plate all the way through the spacers and into the plate, mounting the plate and PCB together.


### Journal #12 : Silkscreen - 2h
I added some silkscreen art, but most of the time came from trying to draw it out. I had a couple of ideas, but eventually ended with this tree design.



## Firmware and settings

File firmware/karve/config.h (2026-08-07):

#pragma once

/*
 * LEFT HALF
 *   COL0..COL7 = GP0..GP7
 *   ROW0..ROW5 = GP8..GP13
 *
 * RIGHT HALF
 *   ROW0..ROW5 = GP5,GP4,GP3,GP2,GP1,GP0
 *   COL0..COL8 = GP14,GP13,GP12,GP11,GP10,GP9,GP8,GP7,GP6
 *
 * BOTH HALVES
 *   split TX = GP16
 *   split RX = GP17
 *   OLED SDA = GP18
 *   OLED SCL = GP19
 *   encoder A = GP20
 *   encoder B = GP21
 */

#define MATRIX_ROWS 12
#define MATRIX_COLS 9


#define DIODE_DIRECTION COL2ROW

#define MATRIX_ROW_PINS { GP8, GP9, GP10, GP11, GP12, GP13 }
#define MATRIX_COL_PINS { GP0, GP1, GP2, GP3, GP4, GP5, GP6, GP7, NO_PIN }

#define MATRIX_ROW_PINS_RIGHT { GP5, GP4, GP3, GP2, GP1, GP0 }
#define MATRIX_COL_PINS_RIGHT { GP14, GP13, GP12, GP11, GP10, GP9, GP8, GP7, GP6 }


#define EE_HANDS

#define SERIAL_USART_FULL_DUPLEX
#define SERIAL_USART_TX_PIN GP16
#define SERIAL_USART_RX_PIN GP17

#define SPLIT_USB_DETECT
#define SPLIT_WATCHDOG_ENABLE
#define SPLIT_WATCHDOG_TIMEOUT 3000

#define SPLIT_LAYER_STATE_ENABLE
#define SPLIT_LED_STATE_ENABLE
#define SPLIT_MODS_ENABLE
#define SPLIT_WPM_ENABLE
#define SPLIT_OLED_ENABLE
#define SPLIT_ACTIVITY_ENABLE

#define ENCODER_A_PINS { GP20 }
#define ENCODER_B_PINS { GP21 }
#define ENCODER_A_PINS_RIGHT { GP20 }
#define ENCODER_B_PINS_RIGHT { GP21 }
#define ENCODER_RESOLUTION 4

#define I2C_DRIVER I2CD1
#define I2C1_SDA_PIN GP18
#define I2C1_SCL_PIN GP19
#define OLED_DISPLAY_ADDRESS 0x3C
#define OLED_BRIGHTNESS 128
#define OLED_TIMEOUT 60000

/* Useful on a Pico during early testing. */
#define RP2040_BOOTLOADER_DOUBLE_TAP_RESET
#define RP2040_BOOTLOADER_DOUBLE_TAP_RESET_TIMEOUT 500U

#define DEBOUNCE 5

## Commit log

2026-07-17 readme update and images
    [bom.csv]
2026-07-17 added step and dxf files
    [bom.csv, left case.step, left pcb.step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]
2026-07-17 added gerbers, kicad files, and bom/cpl files
    [Left Split.kicad_sch, LeftSplit.kicad_sch, RightSplit.kicad_sch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]
2026-07-17 update readme and all kicad-related files
    [karve-split-B_Cu.gbl, karve-split-B_Mask.gbs, karve-split-B_Paste.gbp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]
2026-07-18 Create full bom DO NOT USE FOR PCB.csv
    [full bom DO NOT USE FOR PCB.csv]
2026-07-21 added stl files and organized 3d models
    [left case.step, left case.stl, left pcb.step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]
2026-08-06 Create bom for Macondo.csv
    [bom for Macondo.csv]
2026-08-07 added spacer photo and 3d models, updated readme
    [Spacer.step, Spacer.stl]
2026-08-07 updated readme and bom
    [bom for Macondo.csv]
2026-08-24 updated gerber and kicad files, as well as added journal.md file
    [Left Split.kicad_sch, LeftSplit.kicad_sch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]
2026-08-24 changed files and updated readme
    [full BOM.csv]
2026-08-24 Update full assembly w electronics photo.png
2026-08-26 updated pcb with rounded corners
    [karve-split-B_Cu.gbl, karve-split-B_Mask.gbs, karve-split-B_Paste.gbp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]
